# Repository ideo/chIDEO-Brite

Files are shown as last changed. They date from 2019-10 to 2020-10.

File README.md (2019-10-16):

# chIDEO-Brite

Design files for the chIDEO-Brite interactive display

### Status

Peripherals are set up and working! Deeper functionality now needs to be developed. (More details on status items at the top of `brite_fw.c`)

### Building

Install Arduino IDE (which installs necessary avr tools).

Under `Tools > Board:... > Board Manager` search for and install `megaTinyCore`. this will install necessary header files for the attiny402.

Open terminal and change directories to wherever you cloned/downloaded this project

```
cd firmware
make
```

### Flashing

Uses https://github.com/ElTangas/jtag2updi running on an arduino to program. Change `AVRCONFIG` to point to the `avrdude.conf` inside of that the jtag2updi directory that you cloned/downloaded.

Either alias avrdude as the location of avrdude on your machine, change `avrdude` under `flash:` in the makefile to point to the location of avrdude on your machine (likely wherever your Arduino IDE is isntalled), or install avrdude through homebrew.

Change `PORT` in the makefile to the port of your Aruino running jtag2updi (will likely start with `/dev/cu.usbmodem`)

Open terminal and change directories to wherever you cloned/downloaded this project

```
cd firmware
make flash
```

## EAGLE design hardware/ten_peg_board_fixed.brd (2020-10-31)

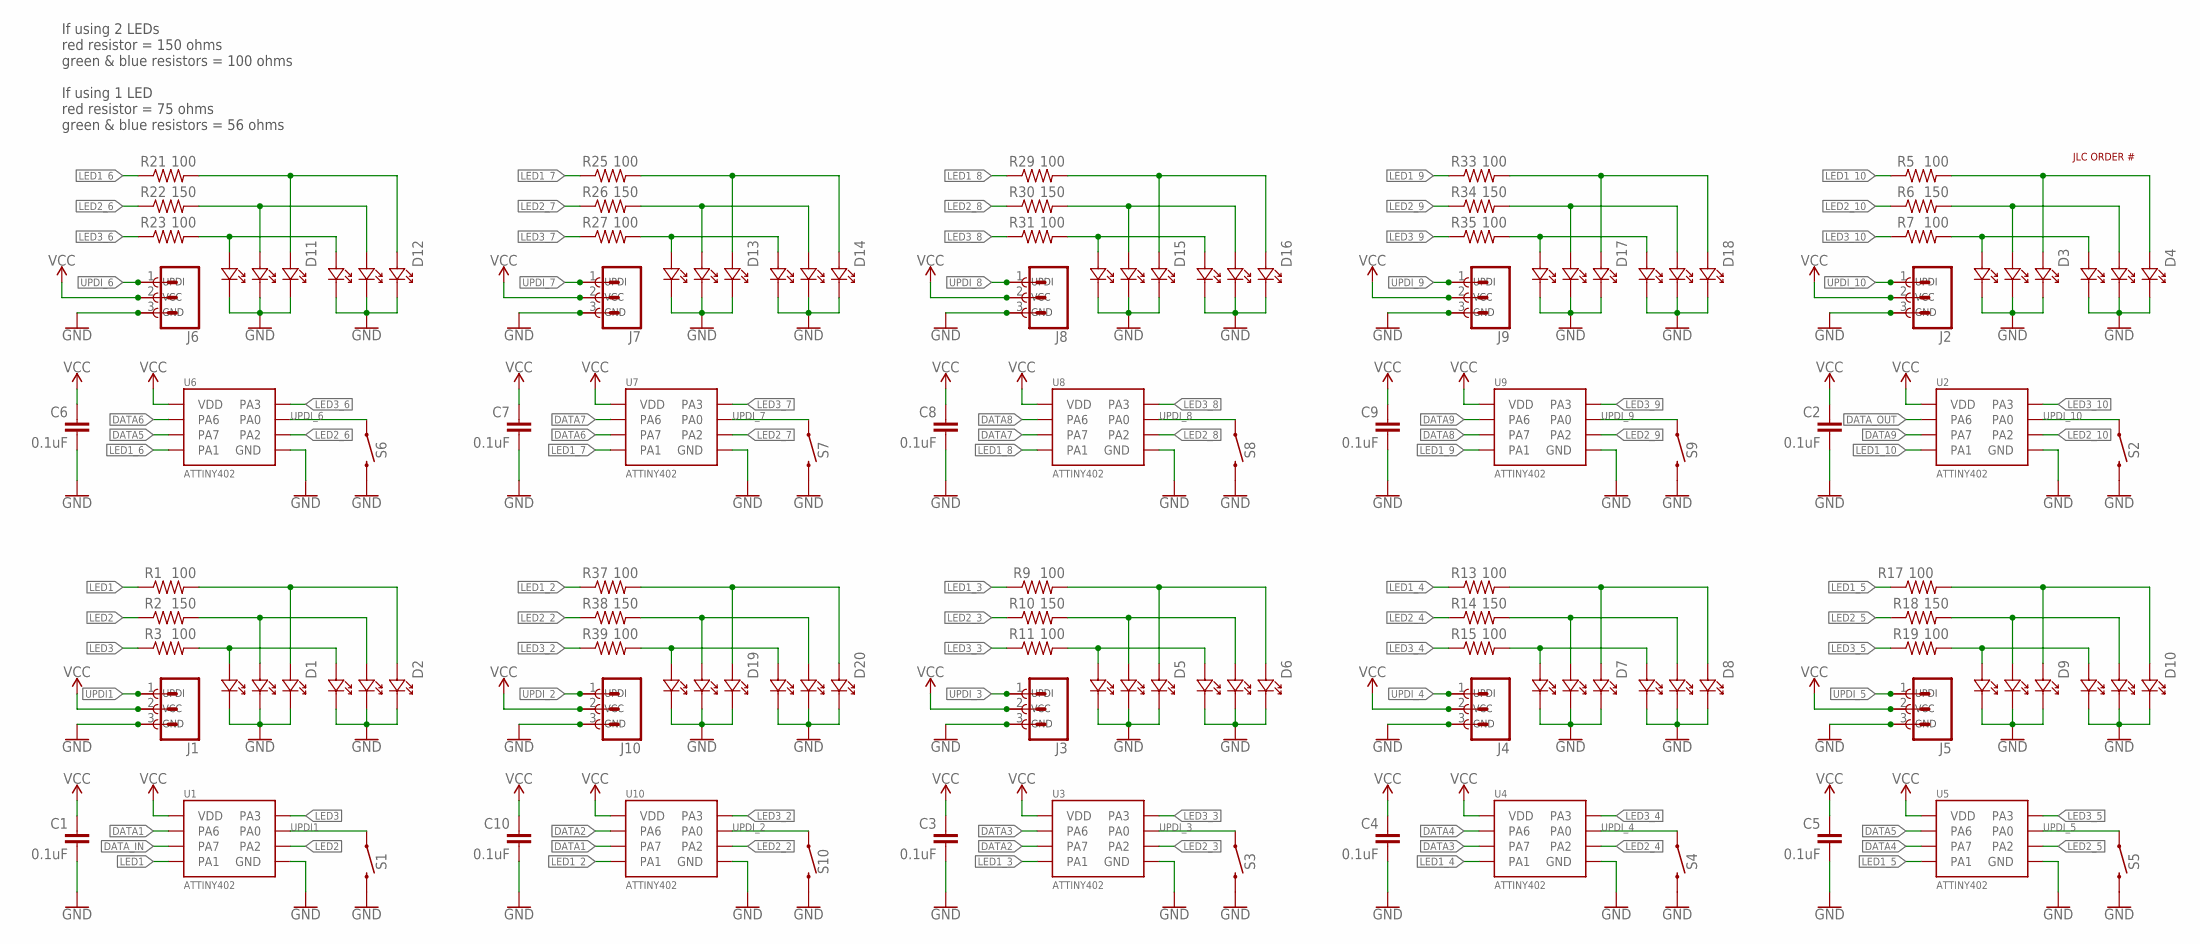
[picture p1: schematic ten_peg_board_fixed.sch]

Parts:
C1, C2, C3, C4, C5, C6, C7, C8, C9, C10: 0.1uF; 0603
D1, D2, D3, D4, D5, D6, D7, D8, D9, D10, D11, D12, D13, D14, D15, D16, D17, D18, D19, D20: 19-337C/RSBHGHC-A88/4T; 6-SMD
J1, J2, J3, J4, J5, J6, J7, J8, J9, J10: CONN_03LOCK_LONGPADS; 1X03_LOCK_LONGPADS
R1, R3, R5, R7, R9, R11, R13, R15, R17, R19, R21, R23, R25, R27, R29, R31, R33, R35, R37, R39: 100; 0603
R2, R6, R10, R14, R18, R22, R26, R30, R34, R38: 150; 0603
S1, S2, S3, S4, S5, S6, S7, S8, S9, S10: MOMENTARY-SWITCH-SPST-SMD-4.5MM-WINGED; TACTILE_SWITCH_SMD_4.5MM_WINGED
TP1, TP2, TP3, TP4, TP5, TP6, TP7, TP8, TP9, TP10, TP11, TP12, TP13, TP14, TP15, TP16, TP17, TP18, TP19, TP20, TP21, TP22, TP23, TP24, TP25, TP26, TP27, TP28, TP29, TP30: TEST-POINT3X5; PAD.03X.05
U1, U2, U3, U4, U5, U6, U7, U8, U9, U10: ATTINY402; 8-SOIC
U$1: JLC-ORDER-NUMBER; JLC_ORDER_NUMBER

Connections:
DATA1: U1.P$2 (PA6), U10.P$3 (PA7)
DATA2: U3.P$3 (PA7), U10.P$2 (PA6)
DATA3: U3.P$2 (PA6), U4.P$3 (PA7)
DATA4: U4.P$2 (PA6), U5.P$3 (PA7)
DATA5: U5.P$2 (PA6), U6.P$3 (PA7)
DATA6: U6.P$2 (PA6), U7.P$3 (PA7)
DATA7: U7.P$2 (PA6), U8.P$3 (PA7)
DATA8: U8.P$2 (PA6), U9.P$3 (PA7)
DATA9: U2.P$3 (PA7), U9.P$2 (PA6)
DATA_IN: U1.P$3 (PA7)
DATA_OUT: U2.P$2 (PA6)
GND: C1.2, C2.2, C3.2, C4.2, C5.2, C6.2, C7.2, C8.2, C9.2, C10.2, D1.P$1, D1.P$3, D1.P$5, D2.P$1, D2.P$3, D2.P$5, D3.P$1, D3.P$3, D3.P$5, D4.P$1, D4.P$3, D4.P$5, D5.P$1, D5.P$3, D5.P$5, D6.P$1, D6.P$3, D6.P$5, D7.P$1, D7.P$3, D7.P$5, D8.P$1, D8.P$3, D8.P$5, D9.P$1, D9.P$3, D9.P$5, D10.P$1, D10.P$3, D10.P$5, D11.P$1, D11.P$3, D11.P$5, D12.P$1, D12.P$3, D12.P$5, D13.P$1, D13.P$3, D13.P$5, D14.P$1, D14.P$3, D14.P$5, D15.P$1, D15.P$3, D15.P$5, D16.P$1, D16.P$3, D16.P$5, D17.P$1, D17.P$3, D17.P$5, D18.P$1, D18.P$3, D18.P$5, D19.P$1, D19.P$3, D19.P$5, D20.P$1, D20.P$3, D20.P$5, J1.3, J2.3, J3.3, J4.3, J5.3, J6.3, J7.3, J8.3, J9.3, J10.3, S1.1 (2), S1.4 (2), S2.1 (2), S2.4 (2), S3.1 (2), S3.4 (2), S4.1 (2), S4.4 (2), S5.1 (2), S5.4 (2), S6.1 (2), S6.4 (2), S7.1 (2), S7.4 (2), S8.1 (2), S8.4 (2), S9.1 (2), S9.4 (2), S10.1 (2), S10.4 (2), TP3.P$1, TP6.P$1, TP9.P$1, TP12.P$1, TP15.P$1, TP18.P$1, TP21.P$1, TP24.P$1, TP27.P$1, TP30.P$1, U1.P$8 (GND), U2.P$8 (GND), U3.P$8 (GND), U4.P$8 (GND), U5.P$8 (GND), U6.P$8 (GND), U7.P$8 (GND), U8.P$8 (GND), U9.P$8 (GND), U10.P$8 (GND)
LED1: R1.1, U1.P$4 (PA1)
LED1_2: R37.1, U10.P$4 (PA1)
LED1_3: R9.1, U3.P$4 (PA1)
LED1_4: R13.1, U4.P$4 (PA1)
LED1_5: R17.1, U5.P$4 (PA1)
LED1_6: R21.1, U6.P$4 (PA1)
LED1_7: R25.1, U7.P$4 (PA1)
LED1_8: R29.1, U8.P$4 (PA1)
LED1_9: R33.1, U9.P$4 (PA1)
LED1_10: R5.1, U2.P$4 (PA1)
LED2: R2.1, U1.P$5 (PA2)
LED2_2: R38.1, U10.P$5 (PA2)
LED2_3: R10.1, U3.P$5 (PA2)
LED2_4: R14.1, U4.P$5 (PA2)
LED2_5: R18.1, U5.P$5 (PA2)
LED2_6: R22.1, U6.P$5 (PA2)
LED2_7: R26.1, U7.P$5 (PA2)
LED2_8: R30.1, U8.P$5 (PA2)
LED2_9: R34.1, U9.P$5 (PA2)
LED2_10: R6.1, U2.P$5 (PA2)
LED3: R3.1, U1.P$7 (PA3)
LED3_2: R39.1, U10.P$7 (PA3)
LED3_3: R11.1, U3.P$7 (PA3)
LED3_4: R15.1, U4.P$7 (PA3)
LED3_5: R19.1, U5.P$7 (PA3)
LED3_6: R23.1, U6.P$7 (PA3)
LED3_7: R27.1, U7.P$7 (PA3)
LED3_8: R31.1, U8.P$7 (PA3)
LED3_9: R35.1, U9.P$7 (PA3)
LED3_10: R7.1, U2.P$7 (PA3)
unnamed: D3.P$6, D4.P$6, R7.2
unnamed: D3.P$4, D4.P$4, R6.2
unnamed: D3.P$2, D4.P$2, R5.2
unnamed: D5.P$6, D6.P$6, R11.2
unnamed: D5.P$4, D6.P$4, R10.2
unnamed: D5.P$2, D6.P$2, R9.2
unnamed: D7.P$6, D8.P$6, R15.2
unnamed: D7.P$4, D8.P$4, R14.2
unnamed: D7.P$2, D8.P$2, R13.2
unnamed: D9.P$6, D10.P$6, R19.2
unnamed: D9.P$4, D10.P$4, R18.2
unnamed: D9.P$2, D10.P$2, R17.2
unnamed: D1.P$6, D2.P$6, R3.2
unnamed: D1.P$4, D2.P$4, R2.2
unnamed: D1.P$2, D2.P$2, R1.2
unnamed: D11.P$6, D12.P$6, R23.2
unnamed: D11.P$4, D12.P$4, R22.2
unnamed: D11.P$2, D12.P$2, R21.2
unnamed: D13.P$6, D14.P$6, R27.2
unnamed: D13.P$4, D14.P$4, R26.2
unnamed: D13.P$2, D14.P$2, R25.2
unnamed: D15.P$6, D16.P$6, R31.2
unnamed: D15.P$4, D16.P$4, R30.2
unnamed: D15.P$2, D16.P$2, R29.2
unnamed: D17.P$6, D18.P$6, R35.2
unnamed: D17.P$4, D18.P$4, R34.2
unnamed: D17.P$2, D18.P$2, R33.2
unnamed: D19.P$6, D20.P$6, R39.2
unnamed: D19.P$4, D20.P$4, R38.2
unnamed: D19.P$2, D20.P$2, R37.2
UPDI1: J1.1, S1.2 (1), S1.3 (1), TP25.P$1, U1.P$6 (PA0)
UPDI_2: J10.1, S10.2 (1), S10.3 (1), TP22.P$1, U10.P$6 (PA0)
UPDI_3: J3.1, S3.2 (1), S3.3 (1), TP19.P$1, U3.P$6 (PA0)
UPDI_4: J4.1, S4.2 (1), S4.3 (1), TP16.P$1, U4.P$6 (PA0)
UPDI_5: J5.1, S5.2 (1), S5.3 (1), TP13.P$1, U5.P$6 (PA0)
UPDI_6: J6.1, S6.2 (1), S6.3 (1), TP10.P$1, U6.P$6 (PA0)
UPDI_7: J7.1, S7.2 (1), S7.3 (1), TP7.P$1, U7.P$6 (PA0)
UPDI_8: J8.1, S8.2 (1), S8.3 (1), TP4.P$1, U8.P$6 (PA0)
UPDI_9: J9.1, S9.2 (1), S9.3 (1), TP28.P$1, U9.P$6 (PA0)
UPDI_10: J2.1, S2.2 (1), S2.3 (1), TP1.P$1, U2.P$6 (PA0)
VCC: C1.1, C2.1, C3.1, C4.1, C5.1, C6.1, C7.1, C8.1, C9.1, C10.1, J1.2, J2.2, J3.2, J4.2, J5.2, J6.2, J7.2, J8.2, J9.2, J10.2, TP2.P$1, TP5.P$1, TP8.P$1, TP11.P$1, TP14.P$1, TP17.P$1, TP20.P$1, TP23.P$1, TP26.P$1, TP29.P$1, U1.P$1 (VDD), U2.P$1 (VDD), U3.P$1 (VDD), U4.P$1 (VDD), U5.P$1 (VDD), U6.P$1 (VDD), U7.P$1 (VDD), U8.P$1 (VDD), U9.P$1 (VDD), U10.P$1 (VDD)

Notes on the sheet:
UPDI
VCC
GND
If using 2 LEDs red resistor = 150 ohms green & blue resistors = 100 ohms If using 1 LED red resistor = 75 ohms green & blue resistors = 56 ohms

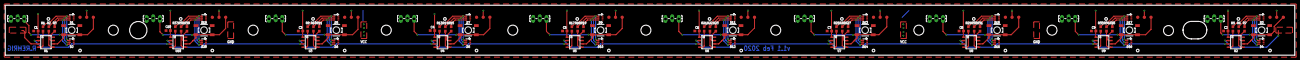
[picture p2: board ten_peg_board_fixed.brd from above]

Board: 2 copper layers, 492.0 x 19.1 mm, 121 parts (1 on the bottom side), 81 nets.

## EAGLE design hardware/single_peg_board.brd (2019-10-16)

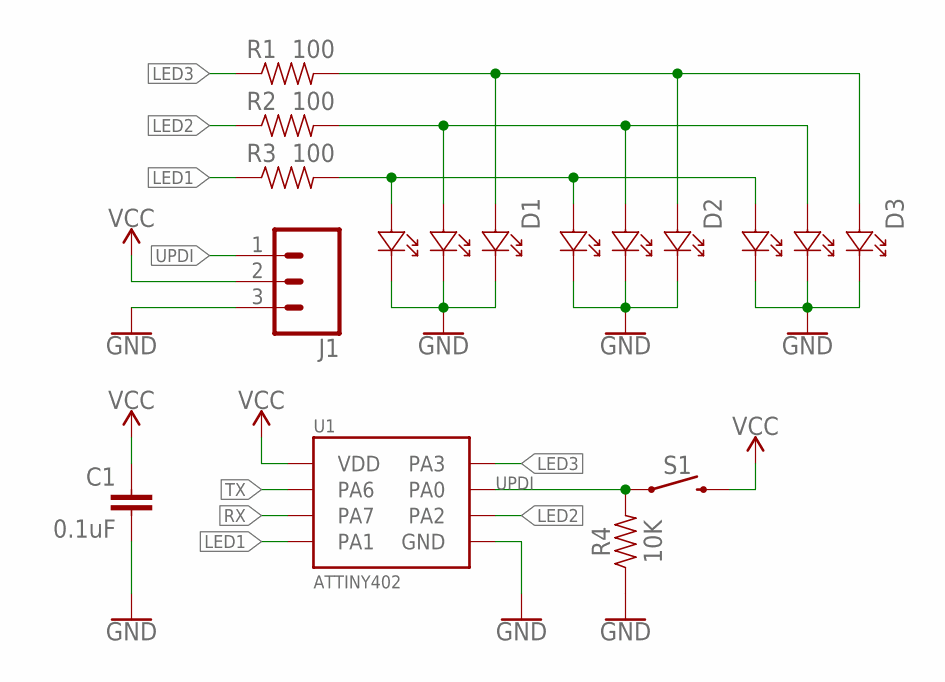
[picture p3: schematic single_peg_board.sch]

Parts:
C1: 0.1uF; 0603
D1, D2, D3: 19-337C/RSBHGHC-A88/4T; 6-SMD
J1: CONN_03LONGPADS; 1X03_LONGPADS
R1, R2, R3: 100; 0603
R4: 10K; 0603
S1: MOMENTARY-SWITCH-SPST-SMD-4.5MM-WINGED; TACTILE_SWITCH_SMD_4.5MM_WINGED
U1: ATTINY402; 8-SOIC

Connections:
GND: C1.2, D1.P$1, D1.P$3, D1.P$5, D2.P$1, D2.P$3, D2.P$5, D3.P$1, D3.P$3, D3.P$5, J1.3, R4.1, U1.P$8 (GND)
LED1: R3.1, U1.P$4 (PA1)
LED2: R2.1, U1.P$5 (PA2)
LED3: R1.1, U1.P$7 (PA3)
unnamed: D1.P$6, D2.P$6, D3.P$6, R3.2
unnamed: D1.P$4, D2.P$4, D3.P$4, R2.2
unnamed: D1.P$2, D2.P$2, D3.P$2, R1.2
RX: U1.P$3 (PA7)
TX: U1.P$2 (PA6)
UPDI: J1.1, R4.2, S1.2 (1), S1.3 (1), U1.P$6 (PA0)
VCC: C1.1, J1.2, S1.1 (2), S1.4 (2), U1.P$1 (VDD)

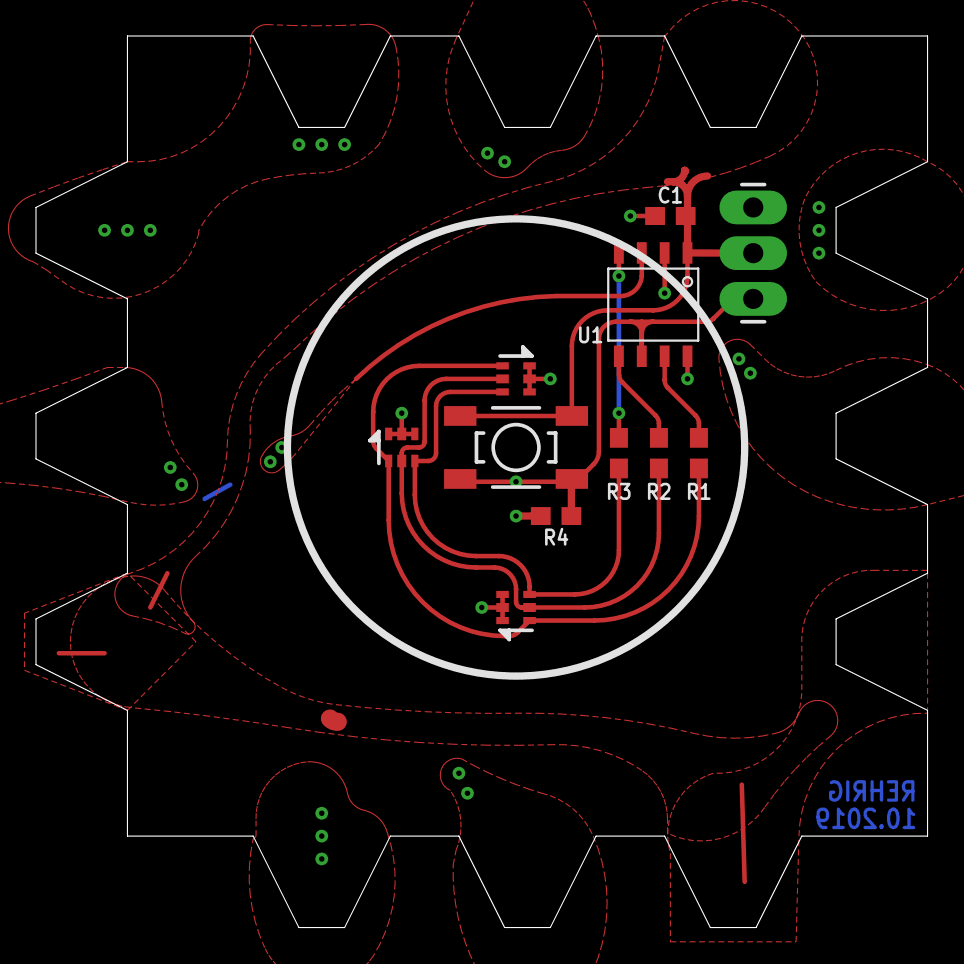
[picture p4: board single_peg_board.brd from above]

Board: 2 copper layers, 49.5 x 49.5 mm, 11 parts (0 on the bottom side), 9 nets.

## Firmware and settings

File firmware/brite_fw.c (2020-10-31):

/**
 * == TODO List ==
 * x PWM working
 * x button working
 * x serial working
 * x eeprom working
 * x interrupts
 *   x button press
 *   x serial receive
 * - serial parsing
 *   x save state
 *   x load state
 *   - set palette
 *     - select which hardcoded palette to use
 *     - save current palette selection to EEPROM
 * - create palettes and hardcode them in
 * x power management
 *   x explore sleep modes (can only idle sleep since TCA won't run in standby =[ )
 *   - explore hw power (resistors, using one LED vs 2 LEDs)
 * x write eeprom after peiod of inactivity to save on lifetime writes
 *           
 * == For Fun ==
 * - pixel drawer
 * 	 - send an initial byte (something like 0xFF that is impossible with multiple command states set) that sets nodes to pixel draw mode
 *   - second command is count til pixel to be drawn
 *   - each time a node receives the count command, it subtracts one from the count and transmits that new value
 *   - if received count is zero, draw pixel (likely white)
 * - whack-a-peg game
 *   - send an initial byte (something like 0xFF that is impossible with multiple command states set) that sets nodes to whack-a-peg mode
 *   - pegs use timer to randomly illuminate peg
 * 	 - when player pushes a lit peg, it turns off and sends a command like 0x01 that lite brite controller can add up for a total score
 *   - send a final byte that sets all nodes back to normal mode
 * 
 * == helpful info ==
 * - Reset pin config https://www.microchip.com/webdoc/GUID-DDB0017E-84E3-4E77-AAE9-7AC4290E5E8B/index.html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
 * - TCA appnote http://ww1.microchip.com/downloads/en/AppNotes/TB3217-Getting-Started-with-TCA-90003217A.pdf
 * - USART http://ww1.microchip.com/downloads/en/DeviceDoc/ATtiny202-402-DataSheet-DS40001969B.pdf
 * - http://www.fourwalledcubicle.com/AVRArticles.php
 *
 * == location of iotn402.h ==
 * 
 *  ‎⁨⁨Applications/⁨Arduino.app/Contents⁩/Java/hardware/tools⁩/avr⁩/avr⁩/include⁩/⁨avr⁩/iotn402.h
 * 
 * == byte structure ==
 * 
 *  xxx xxxxx (LSB)
 *  ||| |
 *  ||| Address (bits 0-4)
 *  ||Palette Command (bit 5)
 *  |Load Command (bit 6)
 *  Save Command (bit 7)
 * 
 *  examples
 *  0x39 = use palette 25
 *  0x4a = load pixel color from EEPROM address 10
 *  0x92 = save pixel color to EEPROM address 18
 * 
 * 	Only one of the command bits (bits 5-7) should be high, to signify the command (save, load, or palette select). The address bits are then used
 *  to identify the EEPROM address to save/load pixel color to/from, or which palette to use. Only one of the command bits high allows for error
 *  checking incase of the command bits gets flipped. An addition to this is 'fun mode' being all command bits high, since two command bit flips is
 *  fairly unlikely, and then using address bits to specify which fun mode to go into, and sending 0xFF ends fun mode.
 *  
 **/

#ifndef F_CPU
#define F_CPU 625000UL // 625kHz clock speed
#endif

#include <avr/io.h>
#include <util/delay.h>
#include <avr/eeprom.h>
#include <avr/interrupt.h>
#include <avr/sleep.h>

/* constants */
static const uint8_t FALSE = 0;
static const uint8_t TRUE  = 1;

static const uint8_t CMD_SAVE = 0x80;
static const uint8_t CMD_LOAD = 0x40;
static const uint8_t CMD_PALT = 0x20;

static const uint8_t EEPROM_TEMP_SAVE  = 0x00;
static const uint8_t EEPROM_SAVE_START = 0x10;

static const uint16_t WAIT_PERIOD = 900; // seconds (15 min)

/* pins */
static const uint8_t BTNPIN = 0;
static const uint8_t BTNMSK = 0x01; // mask for button pin
static const uint8_t BLUPIN = 1;
static const uint8_t REDPIN = 2;
static const uint8_t GRNPIN = 3;
static const uint8_t TXPIN  = 6;
static const uint8_t RXPIN  = 7;

/* global user variables */
// static uint16_t colors[][3] = {{0,0,0}, {50,0,0}, {50,50,0}, {0,50,0}, {0,50,50}, {0,0,50}, {50,0,50}};
static uint16_t colors[][3] = {{0,0,0}, {5,0,0}, {5,5,0}, {0,5,0}, {0,5,5}, {0,0,5}, {5,0,5}}; //GBR
// static uint16_t colors[][3] = {{0,0,1}, {0,0,2}, {0,0,3}, {0,0,4}, {0,0,5}, {0,0,6}, {0,0,7}, {0,0,8}, {0,0,9}};
uint8_t colorIndex;
uint8_t numColors;
uint8_t buttonPressed;
uint16_t secondsCount;


/**** peripheral initialization functions ****/

/**
 * Initialize and configure clock to 625kHz
 **/
void clock_init(void) {
	// set the main clock to internal 20MHz oscillator
	_PROTECTED_WRITE(CLKCTRL.MCLKCTRLA, CLKCTRL_CLKSEL_OSC20M_gc);

	// set the main clock prescaler divisor to 32
	// enable clock prescale
	_PROTECTED_WRITE(CLKCTRL.MCLKCTRLB, CLKCTRL_PDIV_32X_gc | CLKCTRL_PEN_bm);
}

/**
 * Initialize and configure button as input with pull-up
 **/
void button_init(void) {
	// set button pin direction to input
	PORTA.DIRCLR = BTNPIN;

	// enable pull-up and interrupt on falling edge
	// PORTA.PIN0CTRL |= PORT_PULLUPEN_bm | PORT_ISC0_bm | PORT_ISC1_bm;
	PORTA.PIN0CTRL |= PORT_PULLUPEN_bm | PORT_ISC0_bm;
}

/**
 * Initialize and configure LED pins as outputs
 **/
void LEDs_init(void) {
	// set pin direction for LEDs to outputs
	PORTA.DIR |= (1 << BLUPIN) | (1 << REDPIN) | (1 << GRNPIN);
}

/**
 * Initialize and configure Timer/Counter A to control PWM for LEDs
 **/
void TCA0_init(void) {
	// set TCA0 to use original pins (this should be set already by default)
	PORTMUX.CTRLC &= ~PORTMUX_TCA00_bm;

	// enable compare 0,1,2 for PMW generation
	// set TCA0 to dual slope PWM, overflow on BOTTOM
	TCA0.SINGLE.CTRLB = TCA_SINGLE_CMP0EN_bm | TCA_SINGLE_CMP1EN_bm | TCA_SINGLE_CMP2EN_bm | TCA_SINGLE_WGMODE_DSBOTTOM_gc;

	// disable counting on Event input
	TCA0.SINGLE.EVCTRL &= ~(TCA_SINGLE_CNTEI_bm);

	// set period to ~305 Hz (plenty enough for eyes to not see)
	// TCA period = clock freq / (2 * TCA prescaler * desired PWM freq)
	TCA0.SINGLE.PERBUF = 0x40; // 64 steps (6 bit color)
	
	// start with compare buffers set to 0 (PWM off)
	TCA0.SINGLE.CMP0BUF = 0x000;
	TCA0.SINGLE.CMP1BUF = 0x000;
	TCA0.SINGLE.CMP2BUF = 0x000;

	// set clock divider to 16
	// enable TCA0
	TCA0.SINGLE.CTRLA = TCA_SINGLE_CLKSEL_DIV16_gc | TCA_SINGLE_ENABLE_bm;
}

void TCB0_init(void) {
	// set compare value
    TCB0.CCMP = 0x9896; // period of 1 sec

	// set timer mode to periodic interrupt mode
	TCB0.CTRLB = TCB_CNTMODE_INT_gc;

	// set clock to be the same as TCA0
	// enable TCB0
	TCB0.CTRLA = TCB_CLKSEL_CLKTCA_gc | TCB_ENABLE_bm;
    
	// interrupt not enabled until needed
}

/**
 * Initialize and configure USART
 **/
void USART_init(void) {
	// configure USART pin directions
    PORTA.DIR &= ~(1 << RXPIN);
    PORTA.DIR |= (1 << TXPIN);
    
	// set serial baudrate
	// from microchip's getting started with USART:
	// baud freq = (64 * clock freq) / (S * baud)
	// S = number of samples per bit = 16 (normal mode)
	// not really sure, but i think '+ 0.5' is for rounding up
	float baud = 9600;
	uint16_t baudFreq = (uint16_t)((float)((F_CPU << 2) / baud) + 0.5);
	USART0.BAUD = baudFreq;

	// enable interrupt on receive start (necessary for standy mode)
	USART0.CTRLA |= USART_RXCIE_bm;

	// enable TX and RX pins
    USART0.CTRLB |= USART_TXEN_bm | USART_RXEN_bm;
}

/**** functions ****/

void setColor(uint8_t color) {
	TCA0.SINGLE.CMP0BUF = colors[color][0];
	TCA0.SINGLE.CMP1BUF = colors[color][1];
	TCA0.SINGLE.CMP2BUF = colors[color][2];
}

void sendByte(uint8_t data) {
	// wait for data register to be empty
    while (!(USART0.STATUS & USART_DREIF_bm)) {
        ;
    }

	// load data byte to send
    USART0.TXDATAL = data;
}

void loadColor(uint8_t* eepromIndex) {
	// get color from eeprom index
	colorIndex = eeprom_read_byte(eepromIndex);

	if (colorIndex == 255) {
		// eeprom register got reset
		colorIndex = 0;
	}
	else {
		// wrap index if higher than palette count
		colorIndex = colorIndex % numColors;
	}
	
	// set the LEDs
	setColor(colorIndex);
}

uint8_t handleSerial(uint8_t data) {
	// split data into command and index chunks
	uint8_t command = data & 0xE0;
	uint8_t slot = data & 0x1F;

	// handle command
	if (command == CMD_SAVE) {
		// save color to save slot
		uint8_t* saveIndex = (uint8_t *)(EEPROM_SAVE_START + slot);
		eeprom_update_byte(saveIndex, colorIndex);
	}
	else if (command == CMD_LOAD) {
		// load color from save slot
		uint8_t* eepromIndex = (uint8_t *)(EEPROM_SAVE_START + slot);
		loadColor(eepromIndex);
	}
	else if (command == CMD_PALT) {
		// load palette
	}
	else {
		// oh no! there was an error
		return 1;
	}

	return 0;
}

void handleError(void) {
	// flash red and off to show error
	uint8_t flashCount = 5;
	while(flashCount) {
		setColor(5);
		_delay_ms(500);
		setColor(0);
		_delay_ms(500);
		flashCount--;
	}
}

void colorCycle(void) {
	uint16_t maxBright = 500;
	uint8_t steps = 5;

	for (int i=0; i<maxBright; i+=steps) {
		TCA0.SINGLE.CMP0BUF = i;
		TCA0.SINGLE.CMP1BUF = maxBright - i;
		_delay_ms(50);
	}
	for (int i=0; i<maxBright; i+=steps) {
		TCA0.SINGLE.CMP2BUF = i;
		TCA0.SINGLE.CMP0BUF = maxBright - i;
		_delay_ms(50);
	}
	for (int i=0; i<maxBright; i+=steps) {
		TCA0.SINGLE.CMP1BUF = i;
		TCA0.SINGLE.CMP2BUF = maxBright - i;
		_delay_ms(50);
	}
}

/**** interrupt functions ****/

/**
 * interrupt service routine for portA pin event
 **/
ISR(PORTA_PORT_vect, ISR_BLOCK) {
	if (PORTA.INTFLAGS && BTNMSK) {
		if ((~PORTA.IN & BTNMSK) && !buttonPressed) {
			// flag to ensure button press only counts once
			buttonPressed = TRUE;

			// increment palette to next color
			colorIndex++;
			if (colorIndex >= numColors) { colorIndex = 0; }

			// set color
			setColor(colorIndex);

			// debounce
			_delay_ms(50);

			// start timer for eeprom update
    		TCB0.INTCTRL &= ~TCB_CAPT_bm;
			secondsCount = 0;
    		TCB0.INTCTRL |= TCB_CAPT_bm;
		}
		else if ((PORTA.IN & BTNMSK) && buttonPressed) {
			// clear flag
			buttonPressed = FALSE;

			// debounce
			_delay_ms(50);
		}
		
		// clear the interrupt flag
		PORTA.INTFLAGS |= BTNMSK;
	}
}

/**
 * interrupt service routine for USART receive complete event
 **/
ISR(USART0_RXC_vect, ISR_BLOCK) {
	// check for receive to complete
	while (!(USART0.STATUS & USART_RXCIF_bm)) {
		;
	}
	
	// get the received byte
	uint8_t rxByte = USART0.RXDATAL;

	if(handleSerial(rxByte) == 0) {
		// relay byte
		sendByte(rxByte);
	}
	else {
		// on no! there was an error
		handleError();
		setColor(colorIndex);
	}
}

/**
 * interrupt service routine for TCB timer trigger
 * 
 * TCB timer is used to store the pixel value after WAIT_PERIOD
 * this prevents the EEPROM temp address from wearing out as fast due to less write cycles
 **/
ISR(TCB0_INT_vect) {
	secondsCount++;

	// check if it's been long enough to save current value to temp register
	if (secondsCount >= WAIT_PERIOD) {
		// write color selection to eeprom temp slot if different than previous
		eeprom_update_byte((uint8_t *)0, colorIndex);

		// clear count
		secondsCount = 0;
		
		// disable TCB0 interrupt until color changed again
    	TCB0.INTCTRL &= ~TCB_CAPT_bm;
	}
	
	TCB0.INTFLAGS = TCB_CAPT_bm; /* Clear the interrupt flag */
}

/**** main function ****/

int main (void){
	clock_init();
	TCA0_init();
	TCB0_init();
	LEDs_init();
	button_init();
	USART_init();

	// give USART receive complete highest interrupt priority
	CPUINT.LVL0PRI = USART0_RXC_vect_num;
	
	// quick delay while configurations take effect
	_delay_ms(10);
	
	// configure global variables
	numColors = sizeof(colors)/sizeof(colors[0]);
	buttonPressed = FALSE;
	secondsCount = 0;

	// recall and set last color
	loadColor(0);

	// enable interrupts
	sei();

	// configure sleep mode to idle when entered
	SLPCTRL.CTRLA |= SLPCTRL_SMODE_IDLE_gc;

	while(1){
		sleep_enable();
		sleep_cpu();
		; // everything is handled by interrupts :D
	}
}

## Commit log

2019-10-16 initial commit - basic functionality
    [single_peg_board.brd, single_peg_board.sch]
2019-10-17 add interrupts
2019-10-18 add save/load to/from memory slot serial command
2020-03-11 add newest board layouts
    [programmer_header.brd, programmer_header.sch, ten_peg_board.brd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]
2020-10-31 add color picker and add more comments
    [ten_peg_board_fixed.brd, ten_peg_board_fixed.sch]

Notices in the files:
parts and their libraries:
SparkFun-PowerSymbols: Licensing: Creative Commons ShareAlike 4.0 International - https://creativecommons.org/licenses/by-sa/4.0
